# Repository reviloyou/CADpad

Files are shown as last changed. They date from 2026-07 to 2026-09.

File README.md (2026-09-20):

# CAD-hackpad
A macropad made to optimize commonly used commands/actions in Soldiworks CAD. Claude used for the program export onto the CADpad

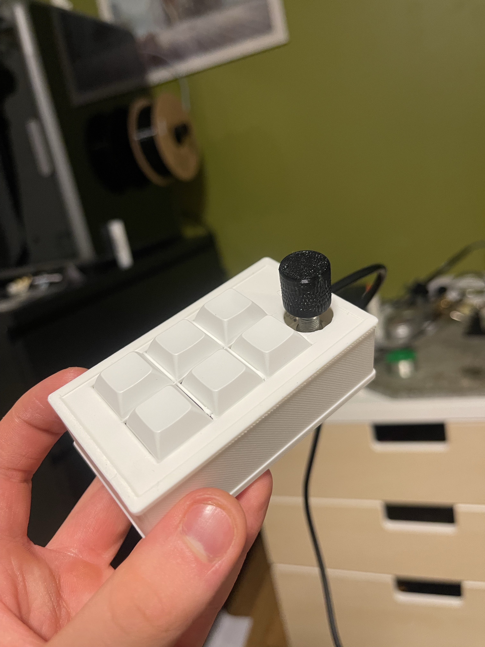
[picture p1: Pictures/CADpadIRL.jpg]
CADpad built


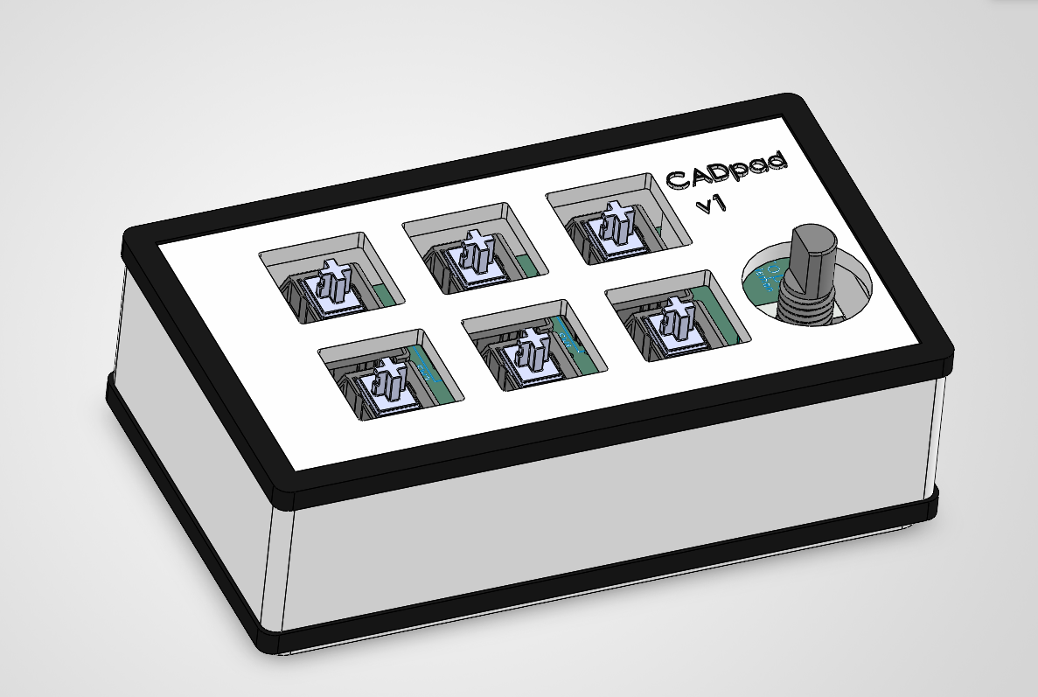
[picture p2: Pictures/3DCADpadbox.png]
3D picture of the CADpad box


## Simple-ish explanation of project
It is split up into 6 buttons and 1 knob with diffrent purposes. This includes a button for choosing the plane/a plane, sketching on that plane, extruding as well as cutting and a simple enter button. Then its onto the last button and knob, the knobs rotation is used for adjusting numbers up and down in intervalls of (1-10-25)mm. Adjusting the interval is done with the button and the rotary encoder button is used for rounding this chosen number in solidworks to the closest 10. 

This project is supposed to effectivize CAD work but wont replace a regular keyboard and mouse. It bypasses some of the most repetetive mouse clicks that are usual for solidworks or CAD in general.

## Case assembly
The case assembly is split into a simple top and bottom. This can be 3D printed and is made so that this sanwich ice-cream looking hackpad doesnt feature any visible screws. On the top part of the case you can see 3 holes: these holes are intended to fit the guide-stick on the bottom case, as well as, 2 M3 heat innset. This makes it so that the screws can be secured safely and threaded through the bottom case making it so that no screws are visible. For assembly after getting the heatset innserts put in is simple: Line up the soldered PCB pointing seeduino down and beeing able to read "thy barbiemann", you also have to make sure that the seeduino is pointed towards the output port. Then you simply have 2 screws for easy accessibility.

## Bill of materials
1x XIAO RP2040
6x Cherry MX Switches
6x Blank DSA Keycaps
1x EC11 20mm Rotary Encoders
2x M3x16 Bolt
2x M3 Heatset

## Schematic (a little messy)

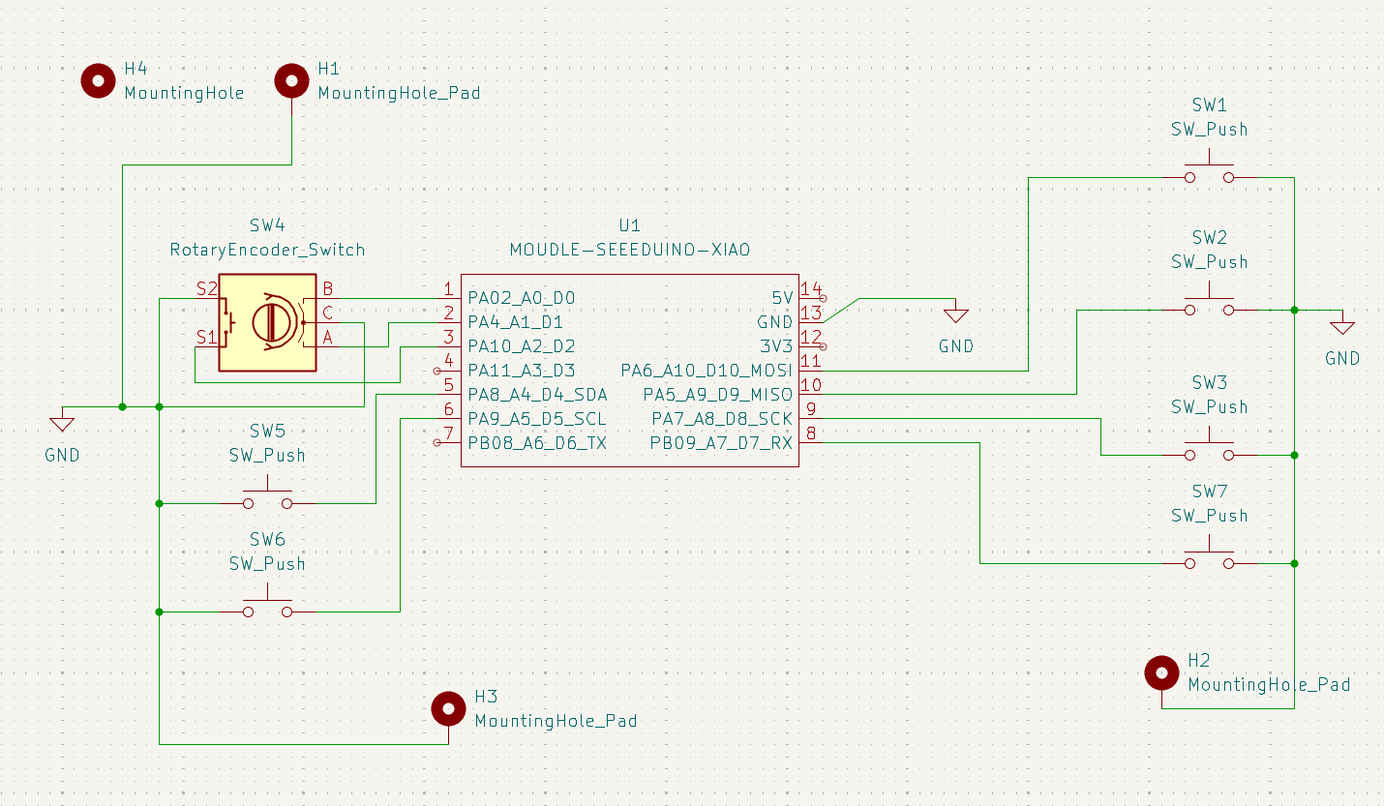
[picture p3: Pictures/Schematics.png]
Macropad schematics


## PCB

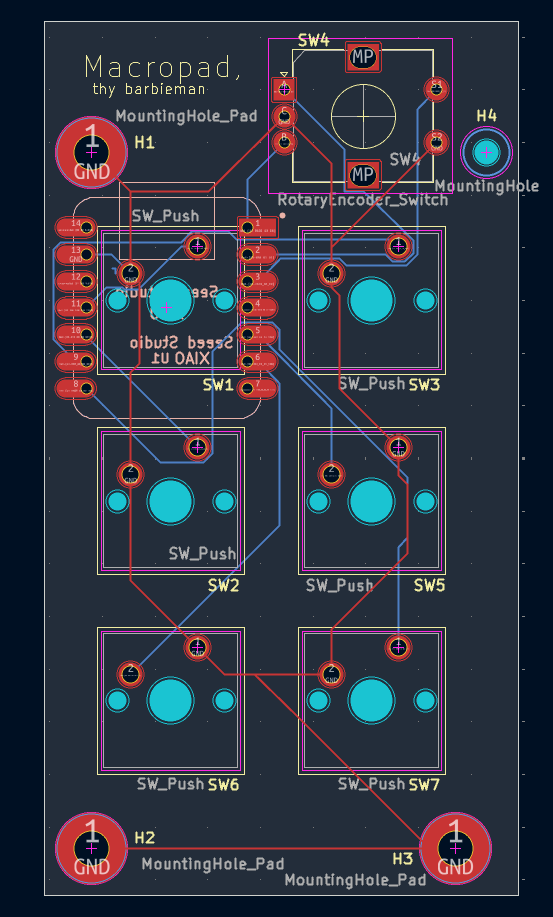
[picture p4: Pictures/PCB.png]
Macropad PCB Diagram


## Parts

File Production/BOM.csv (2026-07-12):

Part Name / Description | Quantity | Source Link | Cost Per Unit | Total Cost
Custom PCB (Hackpad) | 1 | https://jlcpcb.com | $15.00 | $15.00
Seeed Studio XIAO RP2040 | 1 | https://seeedstudio.com
Cherry MX Mechanical Switches | 6 | https://sparkfun.com
Blank DSA Keycaps | 6 | https://pimpmykeyboard.com | $1.00 | $6.00
EC11 20mm Rotary Encoder | 1 | https://adafruit.com
M3x16mm Socket Head Bolt | 3 | https://mcmaster.com | $0.20 | $0.60
M3 Brass Heatset Threaded Insert | 3 | https://mcmaster.com | $0.30 | $0.90

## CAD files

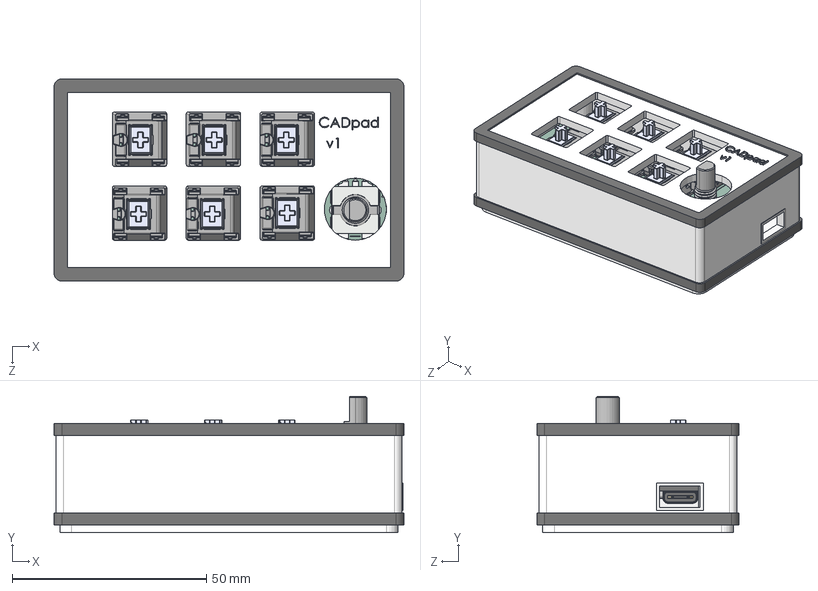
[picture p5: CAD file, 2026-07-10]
CAD-files/Complete CADpad assembly [step-file].STEP
90.0 x 35.0 x 52.0 mm
CADpad - Bottom of case
MX __ ______________1_MX __ ______________1_4.step x 6
MX __ __________________MX __ __________________4.step x 6
MX__ ____ ____ ____2_________2________MX__ ____ ____ ____2_________2________4.step x 6
__________________________________4.step x 6
____________4.step
Shell_4.step
DOUT_4.step
DIN_4.step
VSS_4.step
VDD_4.step
type-c v2_4.step
smd_button v3_4.step
smd_button v3(Mirror)_4.step
COMPOUND_4.step
COMPOUND-0_4.step
Macropad_silkscreen_4.step
Macropad_silkscreen-1_4.step
Macropad_PCB_4.step
CADpad - Top of case

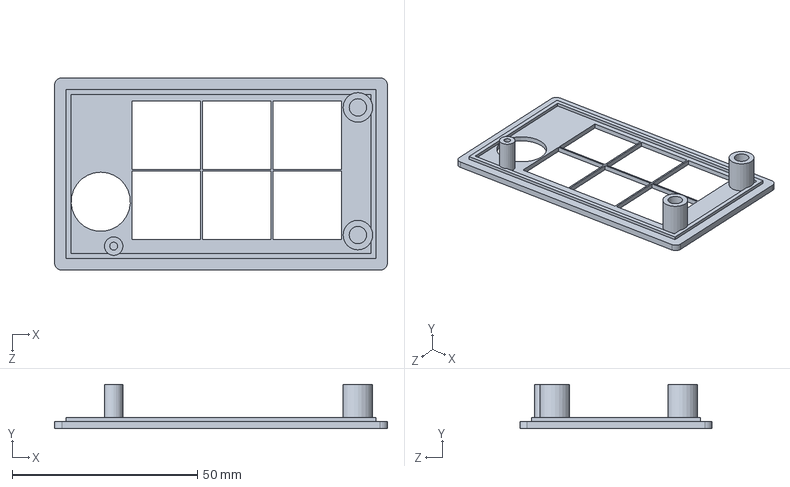
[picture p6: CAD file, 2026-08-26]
CAD-files/CADpad - Top of case.SLDPRT
90.0 x 12.0 x 52.0 mm

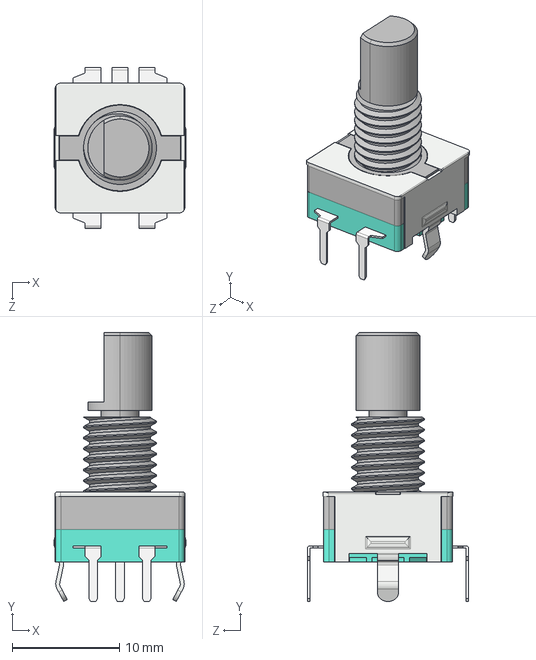
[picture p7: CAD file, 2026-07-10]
PCB-files/extras/3D step models for pcb/Rotary encoder w-switch.STEP
12.3 x 25.1 x 15.0 mm

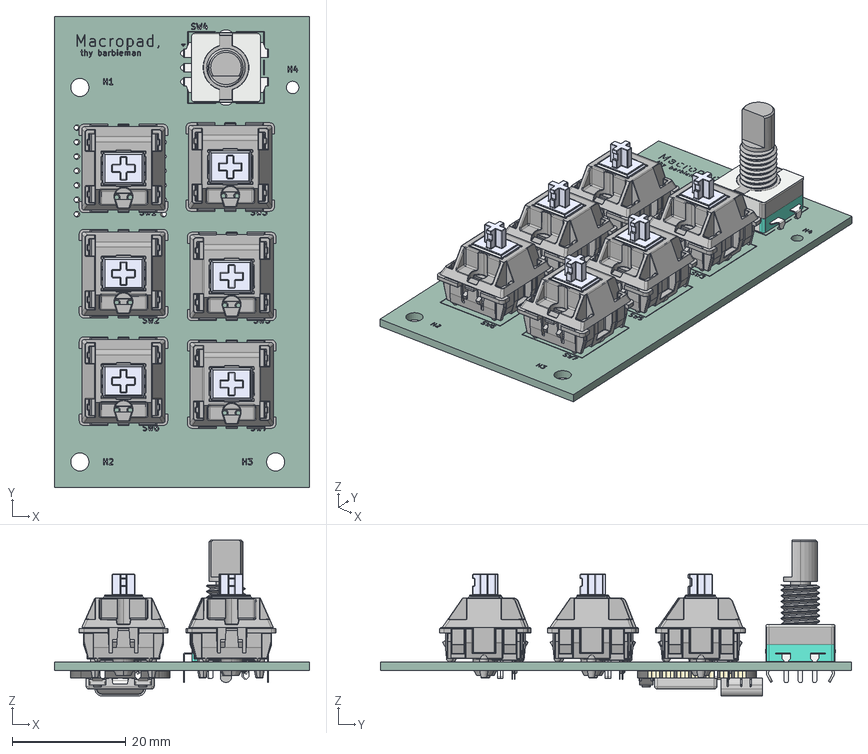
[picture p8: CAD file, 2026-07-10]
PCB-files/extras/PCB with modules [CAD step-file].step
45.0 x 83.0 x 27.5 mm
MX __ ______________1_MX __ ______________1 x 6
MX __ __________________MX __ _________________ x 6
MX__ ____ ____ ____2_________2________MX__ ____ ____ ____2_________2_______ x 6
ѽת±ძǷ
type-c v2
smd_button v3
DOUT
DIN
VSS
VDD
smd_button v3(Mirror)
Macropad_silkscreen x 2
Macropad_PCB

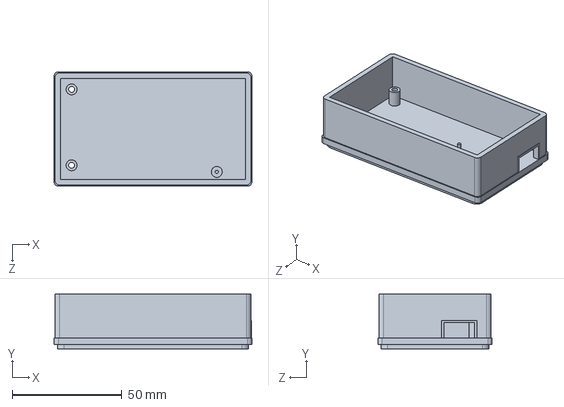
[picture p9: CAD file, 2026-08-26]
CAD-files/CADpad - Bottom of case.SLDPRT
90.0 x 25.0 x 52.0 mm

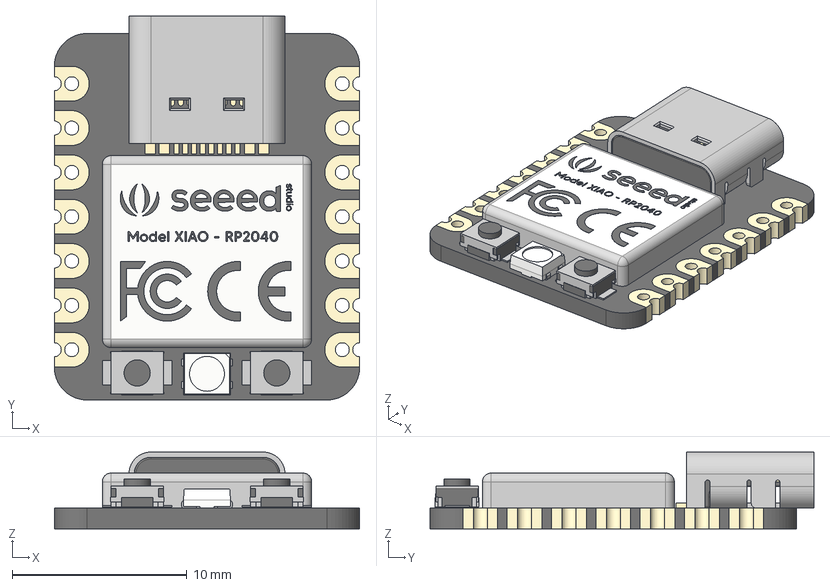
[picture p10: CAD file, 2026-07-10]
PCB-files/extras/3D step models for pcb/Seeed Studio XIAO RP2040 v26.step
17.5 x 22.0 x 4.40 mm
type-c v2
smd_button v3
DOUT
DIN
VSS
VDD
smd_button v3(Mirror)

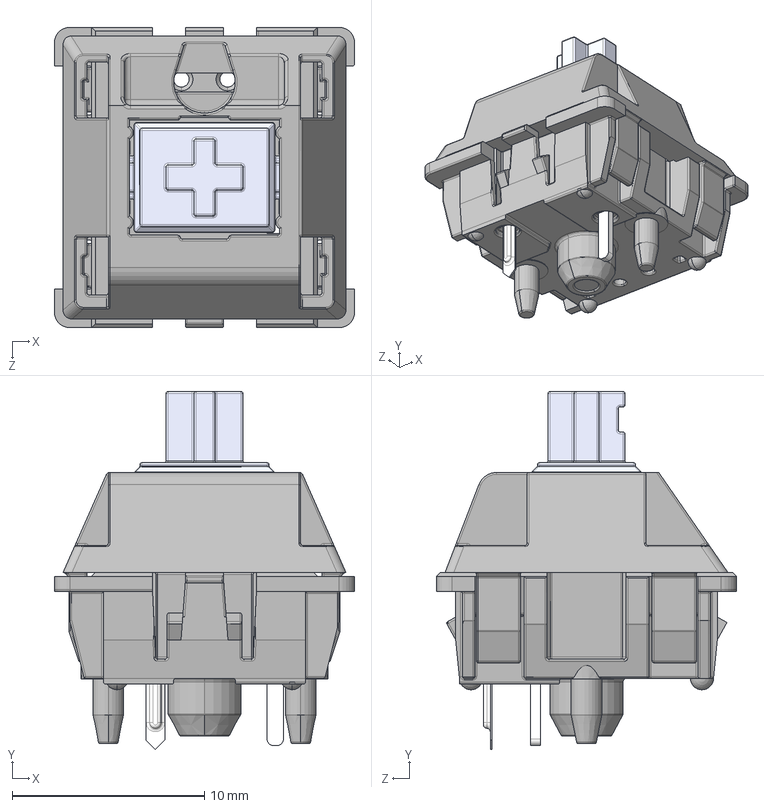
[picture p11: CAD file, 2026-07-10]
PCB-files/extras/3D step models for pcb/MX keyswitch without LED.STEP
15.6 x 18.6 x 15.6 mm
MX __ ______________1_MX __ ______________1
MX __ __________________MX __ _________________
MX__ ____ ____ ____2_________2________MX__ ____ ____ ____2_________2_______

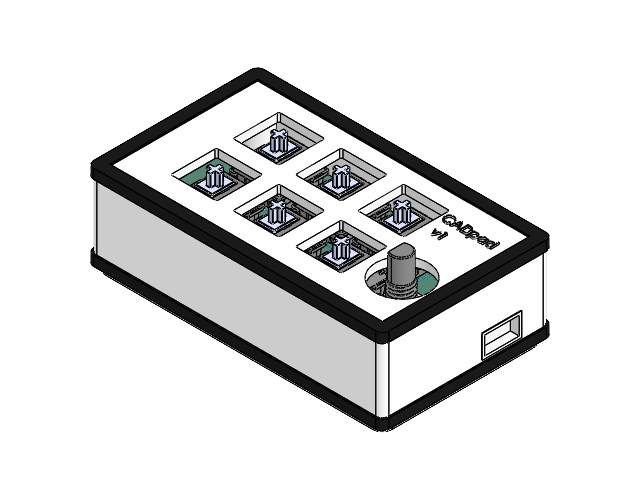
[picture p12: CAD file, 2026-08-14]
CAD-files/Complete CADpad assembly [solidworks].SLDASM
CADpad - Bottom of case
MX __ ______________1_MX __ ______________1_4.step x 6
MX __ __________________MX __ __________________4.step x 6
MX__ ____ ____ ____2_________2________MX__ ____ ____ ____2_________2________4.step x 6
__________________________________4.step x 6
____________4.step
Shell_4.step
DOUT_4.step
DIN_4.step
VSS_4.step
VDD_4.step
type-c v2_4.step
smd_button v3_4.step
smd_button v3(Mirror)_4.step
COMPOUND_4.step
COMPOUND-0_4.step
Macropad_silkscreen_4.step
Macropad_silkscreen-1_4.step
Macropad_PCB_4.step
CADpad - Top of case

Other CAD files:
CAD-files/PCB with modules.SLDASM
Production/CADpad - Top of case [step-file].STEP
Production/CADpad - Bottom of case [step-file].STEP
Production/CADpad - Bottom of case [step-file].3mf

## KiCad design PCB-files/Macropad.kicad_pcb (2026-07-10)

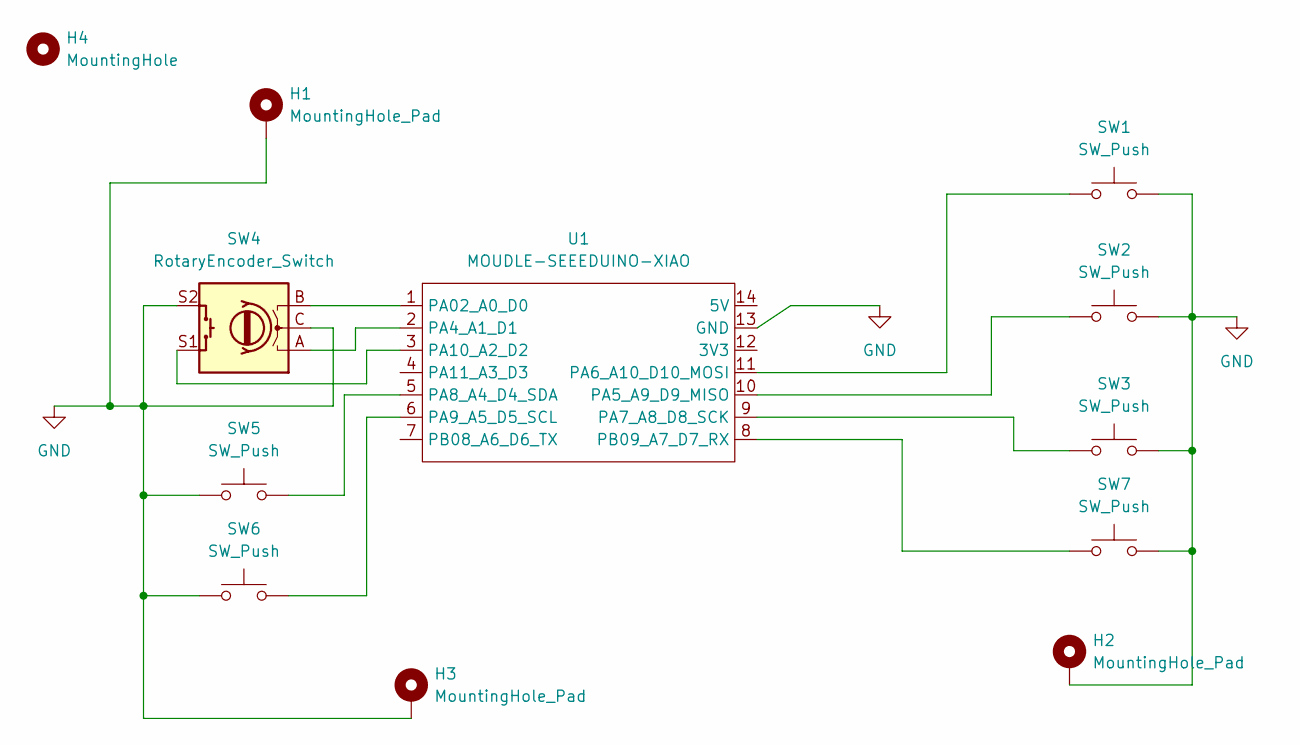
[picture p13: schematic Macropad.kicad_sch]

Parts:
H1, H2, H3: MountingHole_Pad; MountingHole_3.2mm_M3_Pad
H4: MountingHole; MountingHole_2.2mm_M2
SW1, SW2, SW3, SW5, SW6, SW7: SW_Push; SW_Cherry_MX_1.00u_PCB
SW4: RotaryEncoder_Switch; RotaryEncoder_Alps_EC12E-Switch_Vertical_H20mm
U1: MOUDLE-SEEEDUINO-XIAO; XIAO-Generic-Hybrid-14P-2.54-21X17.8MM

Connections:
GND: H1.1 (1_1), H2.1 (1_1), H3.1 (1_1), SW1.2, SW2.2, SW3.2, SW4.C, SW4.S2, SW5.1, SW6.1, SW7.2, U1.13 (GND)
unnamed: SW4.B, U1.1 (PA02_A0_D0)
unnamed: SW4.A, U1.2 (PA4_A1_D1)
unnamed: SW2.1, U1.10 (PA5_A9_D9_MISO)
unnamed: SW1.1, U1.11 (PA6_A10_D10_MOSI)
unnamed: SW3.1, U1.9 (PA7_A8_D8_SCK)
unnamed: SW5.2, U1.5 (PA8_A4_D4_SDA)
unnamed: SW6.2, U1.6 (PA9_A5_D5_SCL)
unnamed: SW4.S1, U1.3 (PA10_A2_D2)
unnamed: SW7.1, U1.8 (PB09_A7_D7_RX)

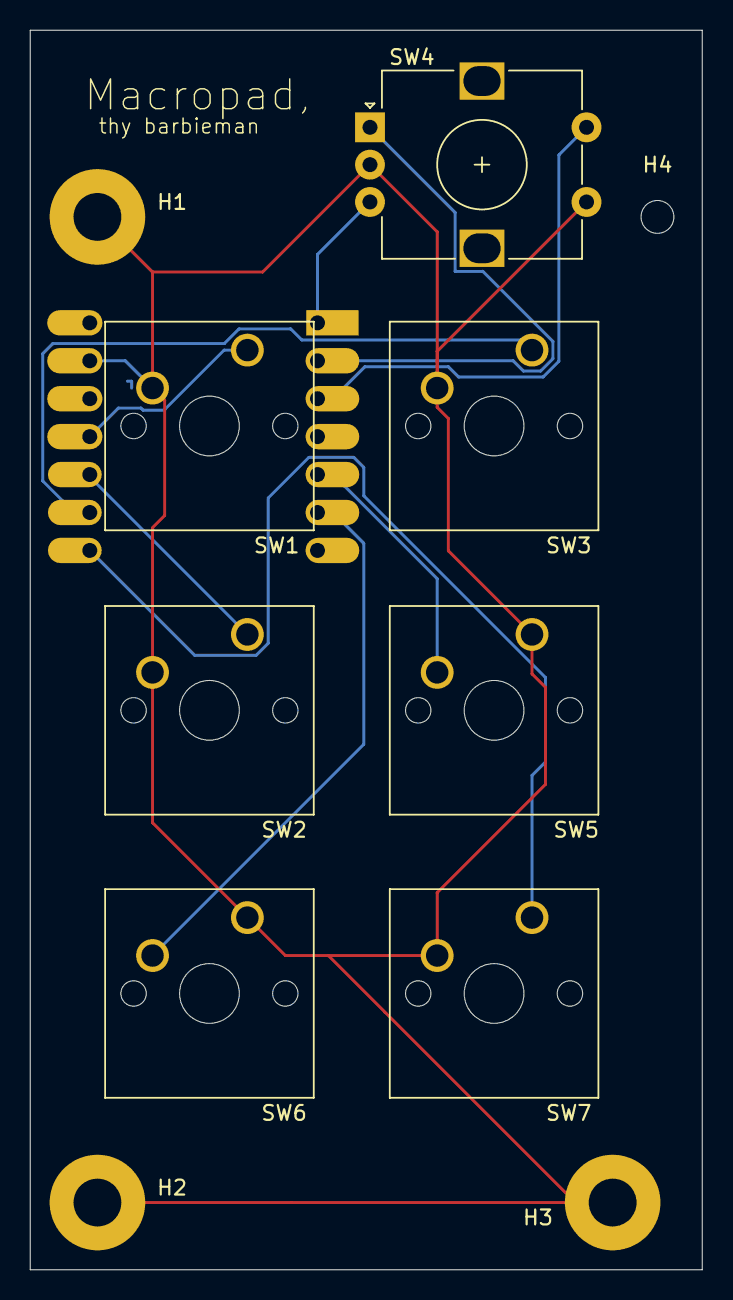
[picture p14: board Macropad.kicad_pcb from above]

Board: 2 copper layers, 45.0 x 83.0 mm, 12 parts (1 on the bottom side), 10 nets.

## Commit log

2026-07-10 The entire project
    So i forgot to contrinously update this as i had it all on my computer and was on vacation. This is now absloutely alll the work
    [CADpad - Bottom of case [step-file].STEP, CADpad - Bottom of case.SLDPRT, CADpad - Top of case [step-file].STEP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]
2026-07-10 Rename Skjermbilde 2026-07-11 004512.png to PCB.png
2026-07-10 Rename Skjermbilde 2026-07-11 004705.png to Schematics.png
2026-08-14 YEs
    fixing what reviwer asked for
    [CADpad - Bottom of case [step-file].STEP, CADpad - Bottom of case.SLDPRT, Complete CADpad assembly [solidworks].SLDASM]
2026-08-26 Building the pad, small adjustments
    [CADpad - Bottom of case [step-file].3mf, CADpad - Bottom of case [step-file].STEP, CADpad - Bottom of case.SLDPRT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]
2026-08-26 more adjustements
    [CADpad - Bottom of case [step-file].3mf, CADpad - Bottom of case [step-file].STEP, CADpad - Bottom of case.SLDPRT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]
2026-08-31 Fix firmware so it compiles, add CI build for the .uf2
    The Firmware/ sources could not be built as-is:
    - info.json defined matrix_pins but no `layouts` block, so the LAYOUT()
    macro both keymaps use did not exist.
    - Both keymaps passed 8 arguments to LAYOUT, but matrix position [3][1]
    has a null pin. Dropped the trailing KC_NO; the pad has 7 real keys
    (6 switches + the encoder button).
    - X_LCTRL no longer exists in QMK master; renamed to X_LCTL.
    Adds a GitHub Actions workflow that grafts Firmware/ into a QMK
    checkout as keyboards/cadpad and compiles both keymaps, publishing
    each .uf2 as a downloadable artifact. External Userspace cannot be
    used here because it only supports keymaps fo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
2026-09-20 CI: always dump build diagnostics as annotations
    make exits 0 in three seconds without producing a binary, so it is
    finding no keyboard and failing silently. Error-only annotations reveal
    nothing in that case.
    Add an always-on diagnostic step reporting whether the CLI can discover
    cadpad, what is in keyboards/cadpad and .build, and the full make output.
2026-09-20 Add the USB descriptor block to keyboard.json
    With the keyboard finally discoverable, the build got as far as
    tmk_core/protocol/usb_descriptor.c and failed:
    error: 'VENDOR_ID' undeclared
    error: 'PRODUCT_ID' undeclared
    error: 'DEVICE_VER' undeclared
    QMK builds the USB device descriptor from keyboard.json's usb block,
    which was absent. Values are arbitrary for a personal build: 0xFEED is
    QMK's generic hobby vendor id.
2026-09-20 Fix pin assignments: D-pad numbers were used as GPIO numbers
    Every pin in keyboard.json was the XIAO's D-pad silkscreen number with a
    GP prefix, but on a XIAO RP2040 those are different numbering schemes.
    Recovered the real wiring from the KiCad netlist:
    SW1 = D10 = GP3 SW2 = D9 = GP4 SW3 = D8 = GP2
    SW5 = D4 = GP6 SW6 = D5 = GP7 SW7 = D7 = GP1
    encoder A = D1 = GP27, B = D0 = GP26, button = D2 = GP28
    The old values hit the wrong switches or unexposed pins: firmware GP3
    (the round macro) is physically SW1, which is why SW1 rounded, and
    GP5/GP8/GP9/GP10 are not broken out at all, so those keys were dead.
    The encoder's A pin and its button were also swapped, an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
